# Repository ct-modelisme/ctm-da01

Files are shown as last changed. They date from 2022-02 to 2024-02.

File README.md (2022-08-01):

# CTM-DA01: Digital Sound Decoder 01

The CTM-DA01 is a sound module for modelrailway projects.
This sound module is compatible with DCC & DC train layouts.

## Licenses

The hardware is released under OpenHardware principes, and the software under OpenSource principes.

 - Hardware (PCB): [Creative Commons Attribution-ShareAlike 4.0 International License](http://creativecommons.org/licenses/by-sa/4.0/)
 - Software (Firmware): [GNU General Public License v3](https://www.gnu.org/licenses/)

## Current releases

 - Hardware (PCB): version 1.0
 - Software (Firmware): version 1.1

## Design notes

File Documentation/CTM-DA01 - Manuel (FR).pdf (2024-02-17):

## CTM-DA01

Décodeur audio configurable

La carte CTM-DA01 est un décodeur sonore, commandable par DCC ou par boutons poussoirs, permettant d’animer votre réseau de quelques bruits ou d’une ambiance sonore.

En cas de bogue, ou simplement si vous avez des suggestions, merci de me contacter à l’adresse :

cyrille.toulet@linux.com

Fonctionnalités

- Commande par DCC ou par boutons poussoirs déportés (optionnel) ;
- Configuration via Cvs ;
- Banque de sons « simples » ;
- Banque de sons à lire en boucle ;
- Banque de sons à lire aléatoirement ;
- Connexion USB série 115 200 bauds (optionnelle).

Montage

Aperçu du montage minimal

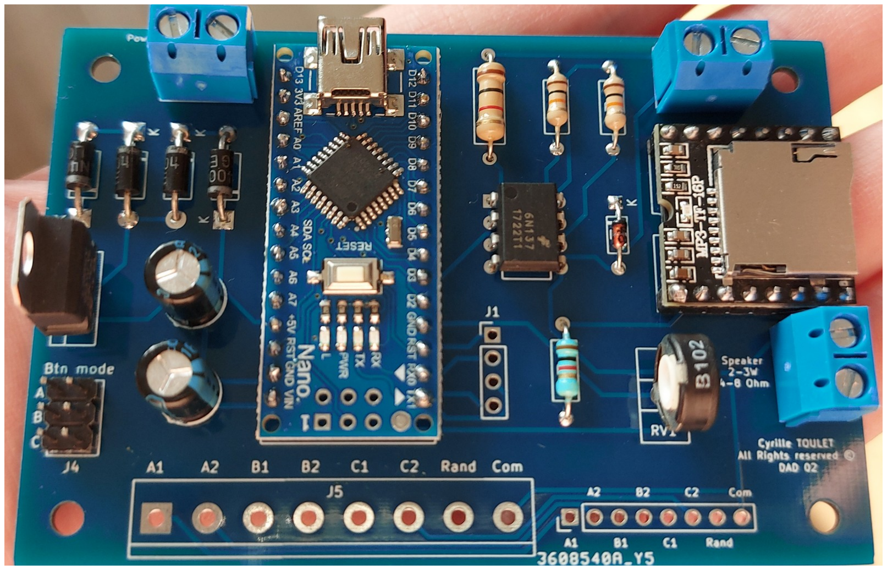
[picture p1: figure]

https://www.ct-modelisme.fr/ | CTM-DA01 | PCB 1.1 – Firmware 1.1

Liste des composants
Références | Composant | Quantité | Description
A1 | Arduino Nano | 1 | Support optionnel
C1, C2 | 220µF/16V ou 47µF/50V | 2
D1, D2, D3, D4 | 1N4007 | 4 | Ou équivalant
D5 | 1N4148 | 1
J1 | Connecteur tulipe 1x4 | 1 | Optionnel
J2, J3, J6 | Bornier à vis 1x2 | 3
J4 | Connecteur tulipe 2x3 | 1
- | Jumper | 0 à 3 | Pour la configuration des boutons
J5 | Bornier à vis 1x8 | 1 | Optionnel
J7 | Connecteur tulipe 1x8 | 1 | Optionnel
R1, R2 | 10kΩ | 2
R3 | 1kΩ (1W) | 1
R4 | 1kΩ | 1
RV1 | Vertical trim pot 1kΩ à 4,7kΩ | 1 | Type B
U1 | LM7805 | 1
U2 | 6N137 | 1
U3 | DFPlayerMini | 1 | Ou autre MP3-TF-16P
- | Carte micro-SD | 1 | Une petite suffira (ex : 2 à 4 Go)
- | Haut parleur 2 à 3 W | 1 | 4 ou 8 Ohm
https://www.ct-modelisme.fr/ | CTM-DA01 | PCB 1.1 – Firmware 1.1

Ordre de montage recommandé

Comme pour n’importe quel circuit électronique, commencez des composants les moins hauts pour terminer sur les plus hauts : diode 1N4148 (D5), puis résistances 1/4 W (toutes sauf R3), puis diodes 1N4007 (D1 à D4) et résistance 1W (R3). Ensuite, supports de CI (s’il y en a), opto-coupleur (U2) et driver audio (U3), connecteurs et borniers à vis, condensateurs 220µF (C1 et C2), trim pot (RV1) et enfin, le régulateur de tension 5V (U1).

Options

En fonction du câblage de votre réseau, vous pouvez opter pour presque chaque entrée/sortie entre utiliser un bornier, utiliser un connecteur tulipe ou à broche, ou encore souder des fils directement à la place du connecteur.

Pour rendre démontable l’arduino, vous pouvez également ajouter les supports femelles préconisés dans la liste des compostants.

Installation

Firmware

Le firmware de cette carte est disponible sur le site de CTM (https://www.ct-modelisme.fr/). Pour l’installer, il suffit de programmer votre Arduino Nano avec le dernier firmware CTM-DA01 en ligne.

Fixation

La carte électronique dispose de 4 trous de montage M3 pour être fixée avec des vis ou des supports adhésifs.

Connexions

Connectez une alimentation de 12 à 15V DC sur le connecteur « Power » (peu importe la polarité). Connectez le bus JK sur le connecteur « DCC » (pas de polarité particulière non plus). Enfin, connectez un haut-parleur de 2 à 3 W en 4 ou 8 Ohm sur le connecteur « Speaker ».

https://www.ct-modelisme.fr/ | CTM-DA01 | PCB 1.1 – Firmware 1.1

Utilisation

Configuration DCC

Ce décodeur audio n’est pas à considérer comme un décodeur d’accessoire, mais comme un décodeur de locomotive à 29 fonctions (F0 à F28).

La configuration de l’adresse s’effectue en modifiant les CVs 17 et 18 du décodeur. La carte est configurée pour utiliser les adresses longues.

Pour s’assurer de la bonne programmation des variables, effectuez deux écritures consécutives de chaque CV.
Attention : Le décodeur est compatible avec l’écriture de CVs, mais pas la lecture. Il est donc

normal de ne pas savoir lire des CVs depuis votre centrale.

Pour réinitialiser le décodeur à sa configuration d’origine (factory reset), modifiez les CVs 7 et 8 à 255.

Liste des CVs
CV(s) | Description | Valeur d’usine
1 | Adresse courte | 3
7 et 8 | Reset quand les valeurs sont à 255 | 0
17 et 18 | Adresse longue | 0 et 3 (adresse 3)

Carte des fonctions DCC
Fonctions | Description
F0 (momentané) | Arrêter la lecture en cours
F1-F10 (momentané) | Jouer le son 1 à 10 correspondant (répertoire 01)
F11-F20 (momentané) | Jouer en boucle le son 1 à 10 correspondant (répertoire 02)
F21 (momentané) | Jouer un son choisi aléatoirement (répertoire 03)
F27 (on/off) | Diminuer le volume
F28 (on/off) | Mute

Réglage du volume max

Le volume maximum (master volume) se règle avec le potentiomètre RV1 sur la carte. Certaines fonctions du décodeur peuvent diminuer le volume, mais jamais l’augmenter.

https://www.ct-modelisme.fr/ | CTM-DA01 | PCB 1.1 – Firmware 1.1

Configuration des boutons

Lorsqu’un contact est fermé entre le commun et un bouton (A/B/C 1/2 et RAND), un son est joué.

Un contact sur le bouton RAND déclenchera un son aléatoire. Pour les boutons A1, A2 , B1, B2, C1 et C2, le son joué dépendra des jumpers placés sur le connecteur J4 (Btn mode).

Sans aucun jumper, les boutons 1/2 correspondants joueront un simple son. Mais si un jumper est installé, les boutons 1/2 correspondants joueront un son en boucle.
Jumper A | Jumper B | Jumper C | Btn A1 | Btn A2 | Btn B1 | Btn B2 | Btn C1 | Btn C2
Non | Non | Non | Simple 1 | Simple 2 | Simple 3 | Simple 4 | Simple 5 | Simple 6
Non | Non | Oui | Simple 1 | Simple 2 | Simple 3 | Simple 4 | Boucle 1 | Boucle 2
Non | Oui | Non | Simple 1 | Simple 2 | Boucle 1 | Boucle 2 | Simple 3 | Simple 4
Non | Oui | Oui | Simple 1 | Simple 2 | Boucle 1 | Boucle 2 | Boucle 3 | Boucle 4
Oui | Non | Non | Boucle 1 | Boucle 2 | Simple 1 | Simple 2 | Simple 3 | Simple 4
Non | Non | Oui | Boucle 1 | Boucle 2 | Simple 1 | Simple 2 | Boucle 3 | Boucle 4
Non | Oui | Non | Boucle 1 | Boucle 2 | Boucle 3 | Boucle 4 | Simple 1 | Simple 2
Oui | Oui | Oui | Boucle 1 | Boucle 2 | Boucle 3 | Boucle 4 | Boucle 5 | Boucle 6

Ajout des sons sur la carte micro-SD

La carte micro-SD doit être formatée en FAT-32.

Elle doit contenir 3 répertoires, nommés respectivement 01, 02 et 03.
Le répertoire 01 contiendra les sons à jouer une seule fois (F1 à F10). Le répertoire 02 contiendra les sons à jouer en boucle (F11 à F20). Enfin, le répertoire 03 contiendra la collections de sons à

jouer aléatoirement (F21).

Les fichiers audio devront être encodés en MP3, et seront nommés 0XX.mp3 ou XX est remplacé par le numéro du fichier.

Par exemple, 001.mp3, 002.mp3, etc.

Attention : les fichiers audio du répertoire 03 (sons aléatoires) doivent impérativement être

nommés dans l’ordre (001.mp3, 002.mp3, etc.) ! Si un fichier intermédiaire devait être supprimé, renommez le dernier du répertoire avec l’ancien nom du fichier effacé afin qu’il y ait une continuité dans les noms de fichiers. Vous pouvez mettre jusqu’à 256 sons dans ce répertoire.

https://www.ct-modelisme.fr/ | CTM-DA01 | PCB 1.1 – Firmware 1.1

Résolution de problèmes

En cas de problème, vous pouvez obtenir des informations de déboguage en connectant la carte DAD-02 à un ordinateur.

Pour cela, connectez l’ordinateur à l’Arduino Nano enfiché sur la carte à l’aide d’un câble USB.

Puis initiez une connexion série à 115 200 bauds à l’aide du moniteur série du SDK Arduino ou de tout autre logiciel série (ex : minicom sous linux).

Exemple de mise en œuvre

Dans cet exemple, nous animerons un passage à niveau situé quelque part dans le sud, entouré d’un promeneur avec son chien, d’un cycliste qui passe non loin de là, et d’une voiture arrivant au niveau du PN.

Arborescence des fichiers sur la carte micro-SD :

## - Répertoire « 01 » :

- Fichier « 001.mp3 » (sonnerie de passage à niveau)
- Fichier « 002.mp3 » (voiture qui démarre)

## - Répertoire « 02 » :

- Fichier « 001.mp3 » (chant des cigales)

## - Répertoire « 03 » :

- Fichier « 001.mp3 » (avion qui survole la zone)
- Fichier « 002.mp3 » (sonnette de vélo)
- Fichier « 003.mp3 » (chouette qui hulotte)
- Fichier « 004.mp3 » (chien qui aboie)

Nous programmons la carte sur l’adresse DCC 1234.

Depuis la centrale, un appui sur la fonction F1 de la « locomotive » 1234 déclenchera la sonnerie du PN. Un appui sur F2 déclenchera le son d’une voiture qui démarre. L’appel à la fonction F11 jouera en boucle le chant des cigales. L’appel à la fonction F21 choisira aléatoirement un son du répertoire « 03 » et le jouera.

Supposons maintenant que le réseau dispose d’un mode « nuit », tamisant l’éclairage. L’activation de la fonction F27 diminuera le volume de lecture, permettant par exemple d’atténuer le chant des cigales.

Enfin, nous installons un bouton poussoir connecté aux broches « COM » et « RAND » de la carte, que l’on installera en façade du réseau. De cette manière, les personnes peuvent elles-mêmes déclencher un son aléatoire en appuyant sur le poussoir.

https://www.ct-modelisme.fr/ | CTM-DA01 | PCB 1.1 – Firmware 1.1

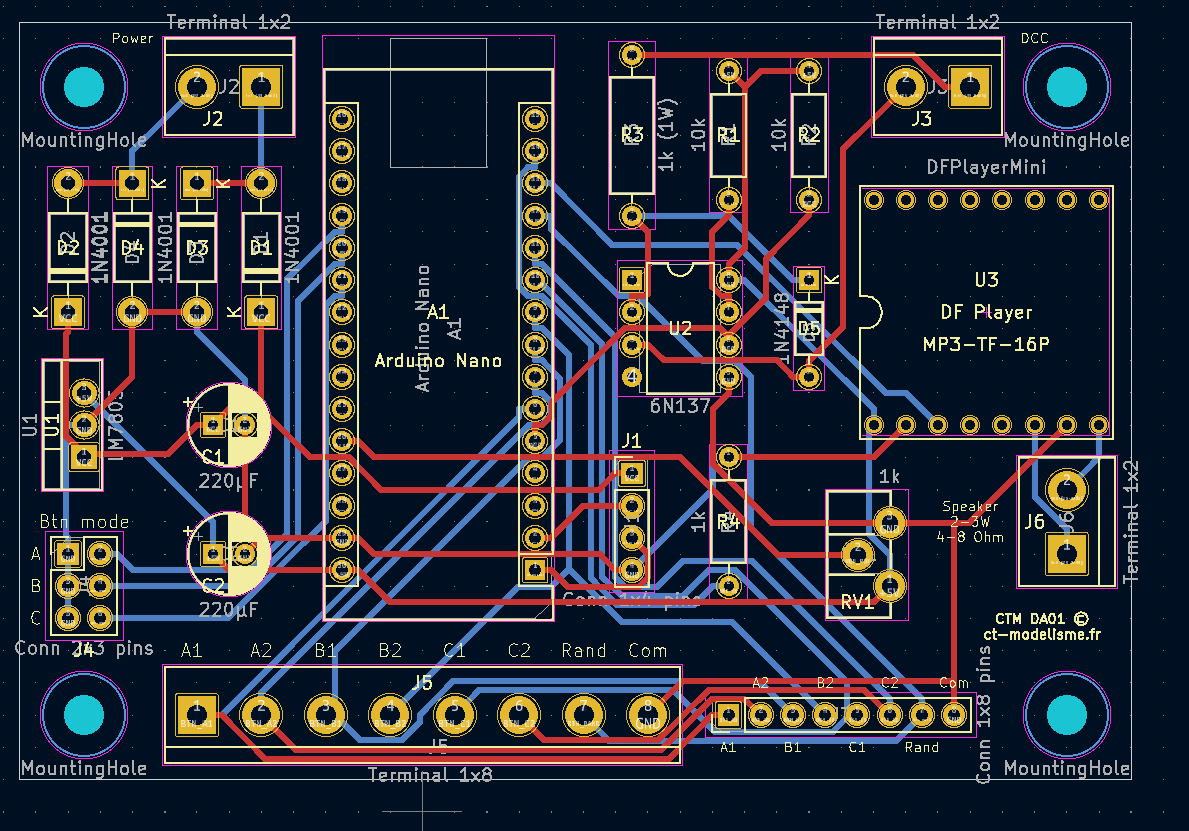
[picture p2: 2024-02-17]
Hardware/Kicad/PCB.png

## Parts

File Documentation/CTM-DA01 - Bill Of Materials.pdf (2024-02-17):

https://ct-modelisme.fr/

Références | Composant | Quantité | Description
A1 | Arduino Nano | 1 | Support optionnel
C1, C2 | 220µF | 2
D1, D2, D3, D4 | 1N4007 | 4 | Ou équivalant
D5 | 1N4148 | 1
J1 | Connecteur tulipe 1x4 | 1 | Optionnel
J2, J3, J6 | Bornier à vis 1x2 | 3
J4 | Connecteur tulipe 2x3 | 1
- | Jumper | 0 à 3 | Pour la configuration des boutons
J5 | Bornier à vis 1x8 | 1 | Optionnel
J7 | Connecteur tulipe 1x8 | 1 | Optionnel
R1, R2 | 10k | 2
R3 | 1k (1W) | 1
R4 | 1k | 1
RV1 | Trim pot 1k (vertical) | 1
U1 | LM7805 | 1
U2 | 6N137 | 1
U3 | DFPlayerMini | 1 | Ou autre MP3-TF-16P
- | Carte micro-SD | 1 | Une petite suffira (ex : 2 à 4 Go)
- | Haut parleur 2 à 3 W | 1 | 4 ou 8 Ohm
- | PCB CTM-DA01 | 1 | Carte électronique CTM-DA01

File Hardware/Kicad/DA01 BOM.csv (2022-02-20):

Source: | /home/iwa/documents/KiCAD/Digital Accessory Decoder/DAD 02/DAD 02/DAD 02.sch
Date: | Mon 23 Aug 2021 12:42:14 PM CEST
Tool: | Eeschema 5.1.10
Generator: | /usr/share/kicad/plugins/bom_csv_grouped_by_value.py
Component Count: | 27
Individual Components:
Item | Qty | Reference(s) | Value | LibPart | Footprint | Datasheet
 |  | A1 | Arduino Nano | MCU_Module:Arduino_Nano_v2.x | Module:Arduino_Nano | https://www.arduino.cc/en/uploads/Main/ArduinoNanoManual23.pdf
 |  | C1 | 220µF | Device:C_Polarized | Capacitor_THT:CP_Radial_D6.3mm_P2.50mm | ~
 |  | C2 | 220µF | Device:C_Polarized | Capacitor_THT:CP_Radial_D6.3mm_P2.50mm | ~
 |  | D1 | 1N4001 | Diode:1N4001 | Diode_THT:D_DO-41_SOD81_P10.16mm_Horizontal | http://www.vishay.com/docs/88503/1n4001.pdf
 |  | D2 | 1N4001 | Diode:1N4001 | Diode_THT:D_DO-41_SOD81_P10.16mm_Horizontal | http://www.vishay.com/docs/88503/1n4001.pdf
 |  | D3 | 1N4001 | Diode:1N4001 | Diode_THT:D_DO-41_SOD81_P10.16mm_Horizontal | http://www.vishay.com/docs/88503/1n4001.pdf
 |  | D4 | 1N4001 | Diode:1N4001 | Diode_THT:D_DO-41_SOD81_P10.16mm_Horizontal | http://www.vishay.com/docs/88503/1n4001.pdf
 |  | D5 | 1N4148 | Diode:1N4148 | Diode_THT:D_DO-35_SOD27_P7.62mm_Horizontal | https://assets.nexperia.com/documents/data-sheet/1N4148_1N4448.pdf
 |  | H1 | MountingHole | Mechanical:MountingHole | MountingHole:MountingHole_3.2mm_M3 | ~
 |  | H2 | MountingHole | Mechanical:MountingHole | MountingHole:MountingHole_3.2mm_M3 | ~
 |  | H3 | MountingHole | Mechanical:MountingHole | MountingHole:MountingHole_3.2mm_M3 | ~
 |  | H4 | MountingHole | Mechanical:MountingHole | MountingHole:MountingHole_3.2mm_M3 | ~
 |  | J1 | Conn 1x4 pins | Connector:Conn_01x04_Male | Connector_PinHeader_2.54mm:PinHeader_1x04_P2.54mm_Vertical | ~
 |  | J2 | Terminal 1x2 | Connector:Screw_Terminal_01x02 | TerminalBlock:TerminalBlock_bornier-2_P5.08mm | ~
 |  | J3 | Terminal 1x2 | Connector:Screw_Terminal_01x02 | TerminalBlock:TerminalBlock_bornier-2_P5.08mm | ~
 |  | J4 | Conn 2x3 pins | Connector_Generic:Conn_02x03_Odd_Even | Connector_PinHeader_2.54mm:PinHeader_2x03_P2.54mm_Vertical | ~
 |  | J5 | Terminal 1x8 | Connector:Screw_Terminal_01x08 | TerminalBlock:TerminalBlock_bornier-8_P5.08mm | ~
 |  | J6 | Terminal 1x2 | Connector:Screw_Terminal_01x02 | TerminalBlock:TerminalBlock_bornier-2_P5.08mm | ~
 |  | J7 | Conn 1x8 pins | Connector:Conn_01x08_Male | Connector_PinHeader_2.54mm:PinHeader_1x08_P2.54mm_Vertical | ~
 |  | R1 | 10k | Device:R | Resistor_THT:R_Axial_DIN0207_L6.3mm_D2.5mm_P10.16mm_Horizontal | ~
 |  | R2 | 10k | Device:R | Resistor_THT:R_Axial_DIN0207_L6.3mm_D2.5mm_P10.16mm_Horizontal | ~
 |  | R3 | 1k (1W) | Device:R | Resistor_THT:R_Axial_DIN0309_L9.0mm_D3.2mm_P12.70mm_Horizontal | ~
 |  | R4 | 1k | Device:R | Resistor_THT:R_Axial_DIN0207_L6.3mm_D2.5mm_P10.16mm_Horizontal | ~
 |  | RV1 | 1k | Device:R_Potentiometer_Trim | Potentiometer_THT:Potentiometer_ACP_CA9-H2,5_Horizontal | ~
 |  | U1 | LM7805 | Regulator_Linear:LM7805_TO220 | Package_TO_SOT_THT:TO-220-3_Vertical | https://www.onsemi.cn/PowerSolutions/document/MC7800-D.PDF
 |  | U2 | 6N137 | Isolator:6N137 | Package_DIP:DIP-8_W7.62mm | https://docs.broadcom.com/docs/AV02-0940EN
 |  | U3 | DFPlayerMini | DAD-02-rescue:DFPlayerMini-Audio | Module:DFRobot_DFPlayerMini_DFR0299 | https://wiki.dfrobot.com/DFPlayer_Mini_SKU_DFR0299
Collated Components:
Item | Qty | Reference(s) | Value | LibPart | Footprint | Datasheet
1 | 1 | A1 | Arduino Nano | MCU_Module:Arduino_Nano_v2.x | Module:Arduino_Nano | https://www.arduino.cc/en/uploads/Main/ArduinoNanoManual23.pdf
2 | 2 | C1, C2 | 220µF | Device:C_Polarized | Capacitor_THT:CP_Radial_D6.3mm_P2.50mm | ~
3 | 4 | D1, D2, D3, D4 | 1N4001 | Diode:1N4001 | Diode_THT:D_DO-41_SOD81_P10.16mm_Horizontal | http://www.vishay.com/docs/88503/1n4001.pdf
4 | 1 | D5 | 1N4148 | Diode:1N4148 | Diode_THT:D_DO-35_SOD27_P7.62mm_Horizontal | https://assets.nexperia.com/documents/data-sheet/1N4148_1N4448.pdf
5 | 4 | H1, H2, H3, H4 | MountingHole | Mechanical:MountingHole | MountingHole:MountingHole_3.2mm_M3 | ~
6 | 1 | J1 | Conn 1x4 pins | Connector:Conn_01x04_Male | Connector_PinHeader_2.54mm:PinHeader_1x04_P2.54mm_Vertical | ~
7 | 3 | J2, J3, J6 | Terminal 1x2 | Connector:Screw_Terminal_01x02 | TerminalBlock:TerminalBlock_bornier-2_P5.08mm | ~
8 | 1 | J4 | Conn 2x3 pins | Connector_Generic:Conn_02x03_Odd_Even | Connector_PinHeader_2.54mm:PinHeader_2x03_P2.54mm_Vertical | ~
9 | 1 | J5 | Terminal 1x8 | Connector:Screw_Terminal_01x08 | TerminalBlock:TerminalBlock_bornier-8_P5.08mm | ~
10 | 1 | J7 | Conn 1x8 pins | Connector:Conn_01x08_Male | Connector_PinHeader_2.54mm:PinHeader_1x08_P2.54mm_Vertical | ~
11 | 2 | R1, R2 | 10k | Device:R | Resistor_THT:R_Axial_DIN0207_L6.3mm_D2.5mm_P10.16mm_Horizontal | ~
12 | 1 | R3 | 1k (1W) | Device:R | Resistor_THT:R_Axial_DIN0309_L9.0mm_D3.2mm_P12.70mm_Horizontal | ~
13 | 1 | R4 | 1k | Device:R | Resistor_THT:R_Axial_DIN0207_L6.3mm_D2.5mm_P10.16mm_Horizontal | ~
14 | 1 | RV1 | 1k | Device:R_Potentiometer_Trim | Potentiometer_THT:Potentiometer_ACP_CA9-H2,5_Horizontal | ~
15 | 1 | U1 | LM7805 | Regulator_Linear:LM7805_TO220 | Package_TO_SOT_THT:TO-220-3_Vertical | https://www.onsemi.cn/PowerSolutions/document/MC7800-D.PDF
16 | 1 | U2 | 6N137 | Isolator:6N137 | Package_DIP:DIP-8_W7.62mm | https://docs.broadcom.com/docs/AV02-0940EN
17 | 1 | U3 | DFPlayerMini | DAD-02-rescue:DFPlayerMini-Audio | Module:DFRobot_DFPlayerMini_DFR0299 | https://wiki.dfrobot.com/DFPlayer_Mini_SKU_DFR0299

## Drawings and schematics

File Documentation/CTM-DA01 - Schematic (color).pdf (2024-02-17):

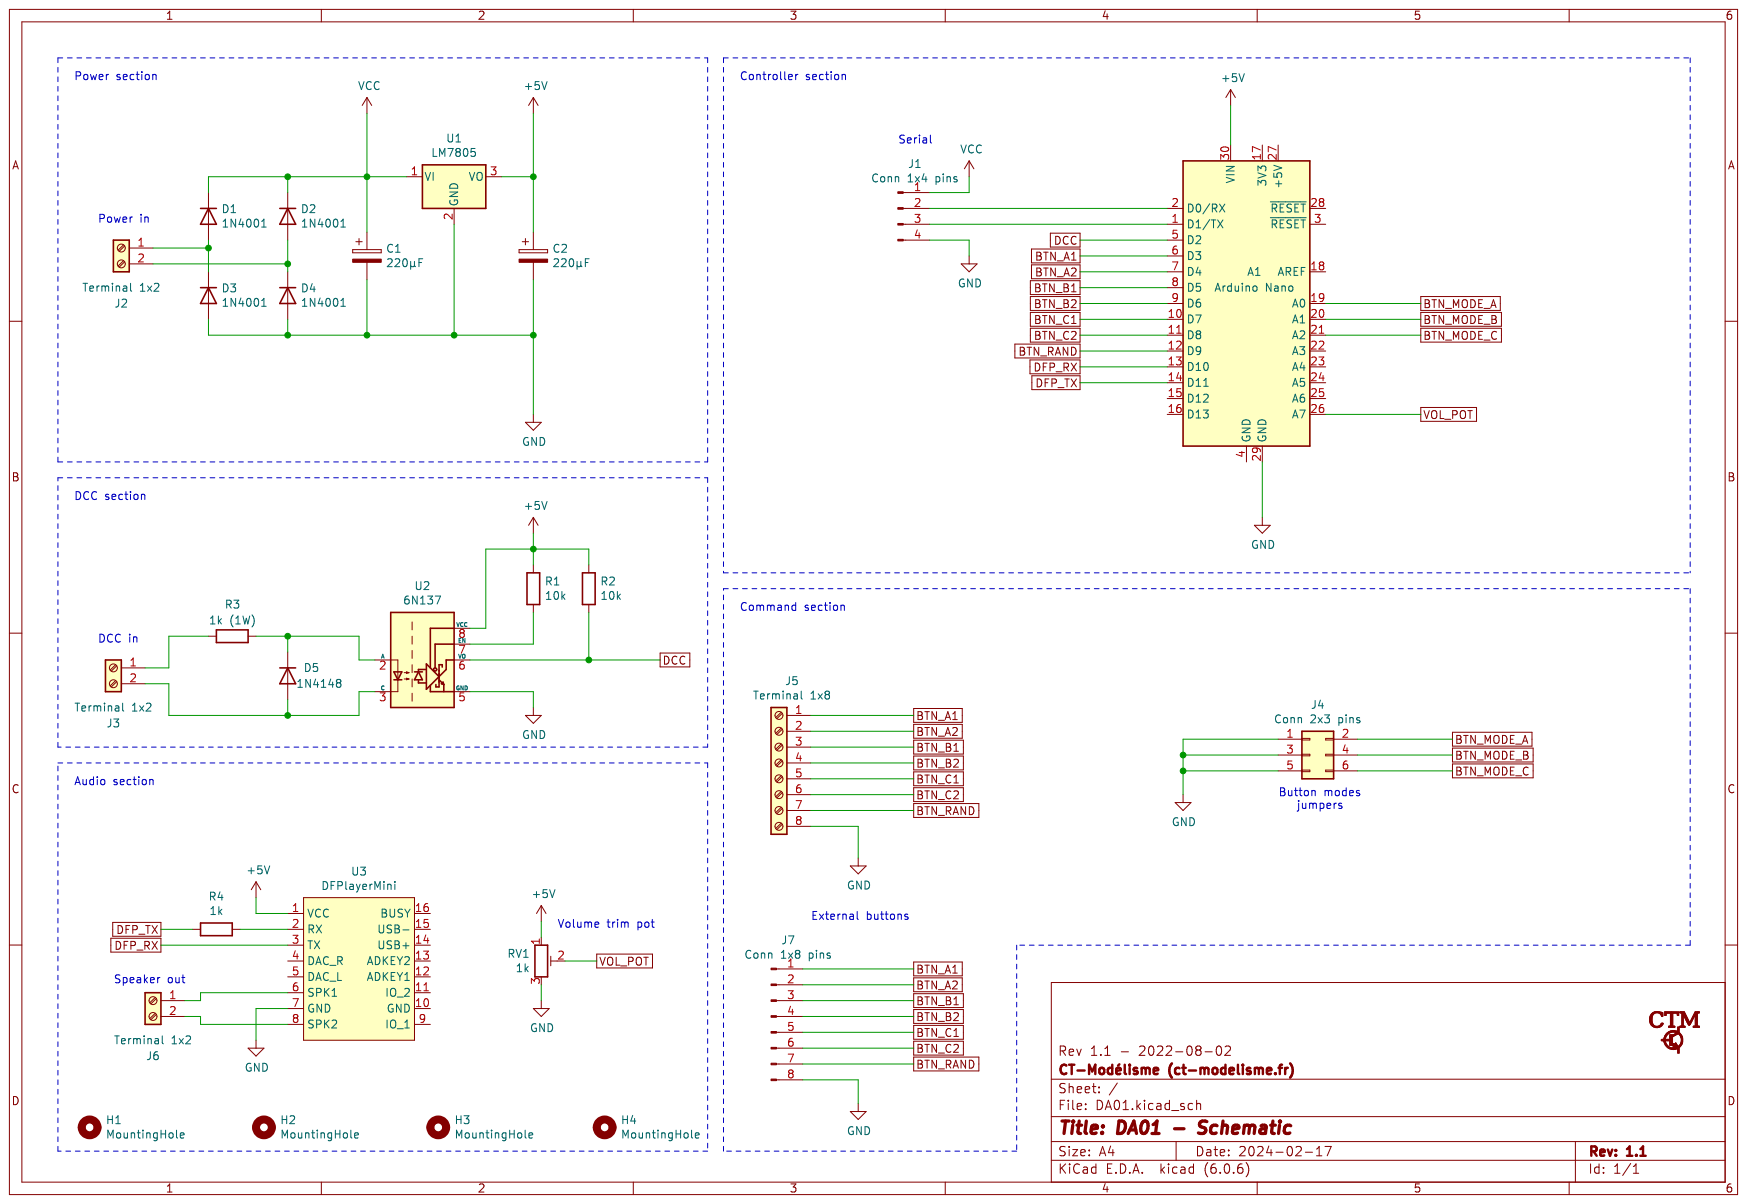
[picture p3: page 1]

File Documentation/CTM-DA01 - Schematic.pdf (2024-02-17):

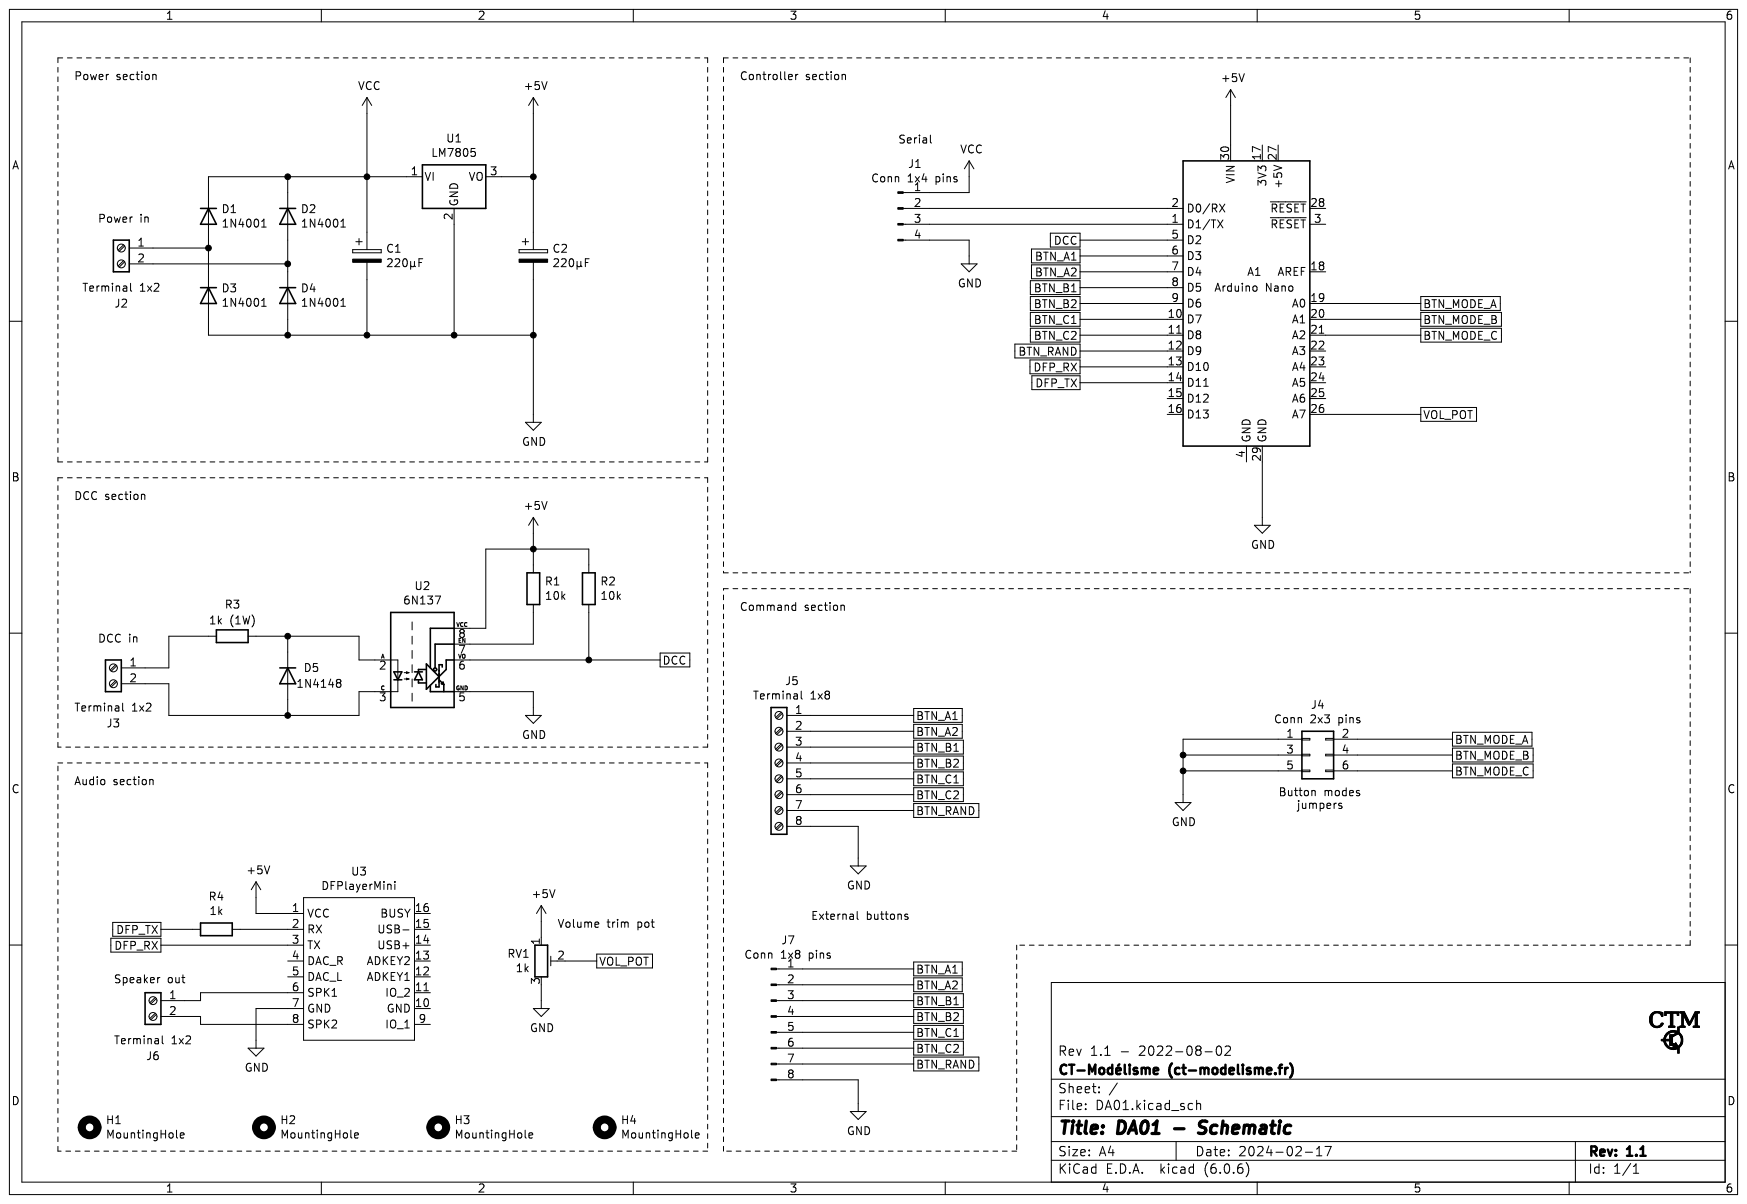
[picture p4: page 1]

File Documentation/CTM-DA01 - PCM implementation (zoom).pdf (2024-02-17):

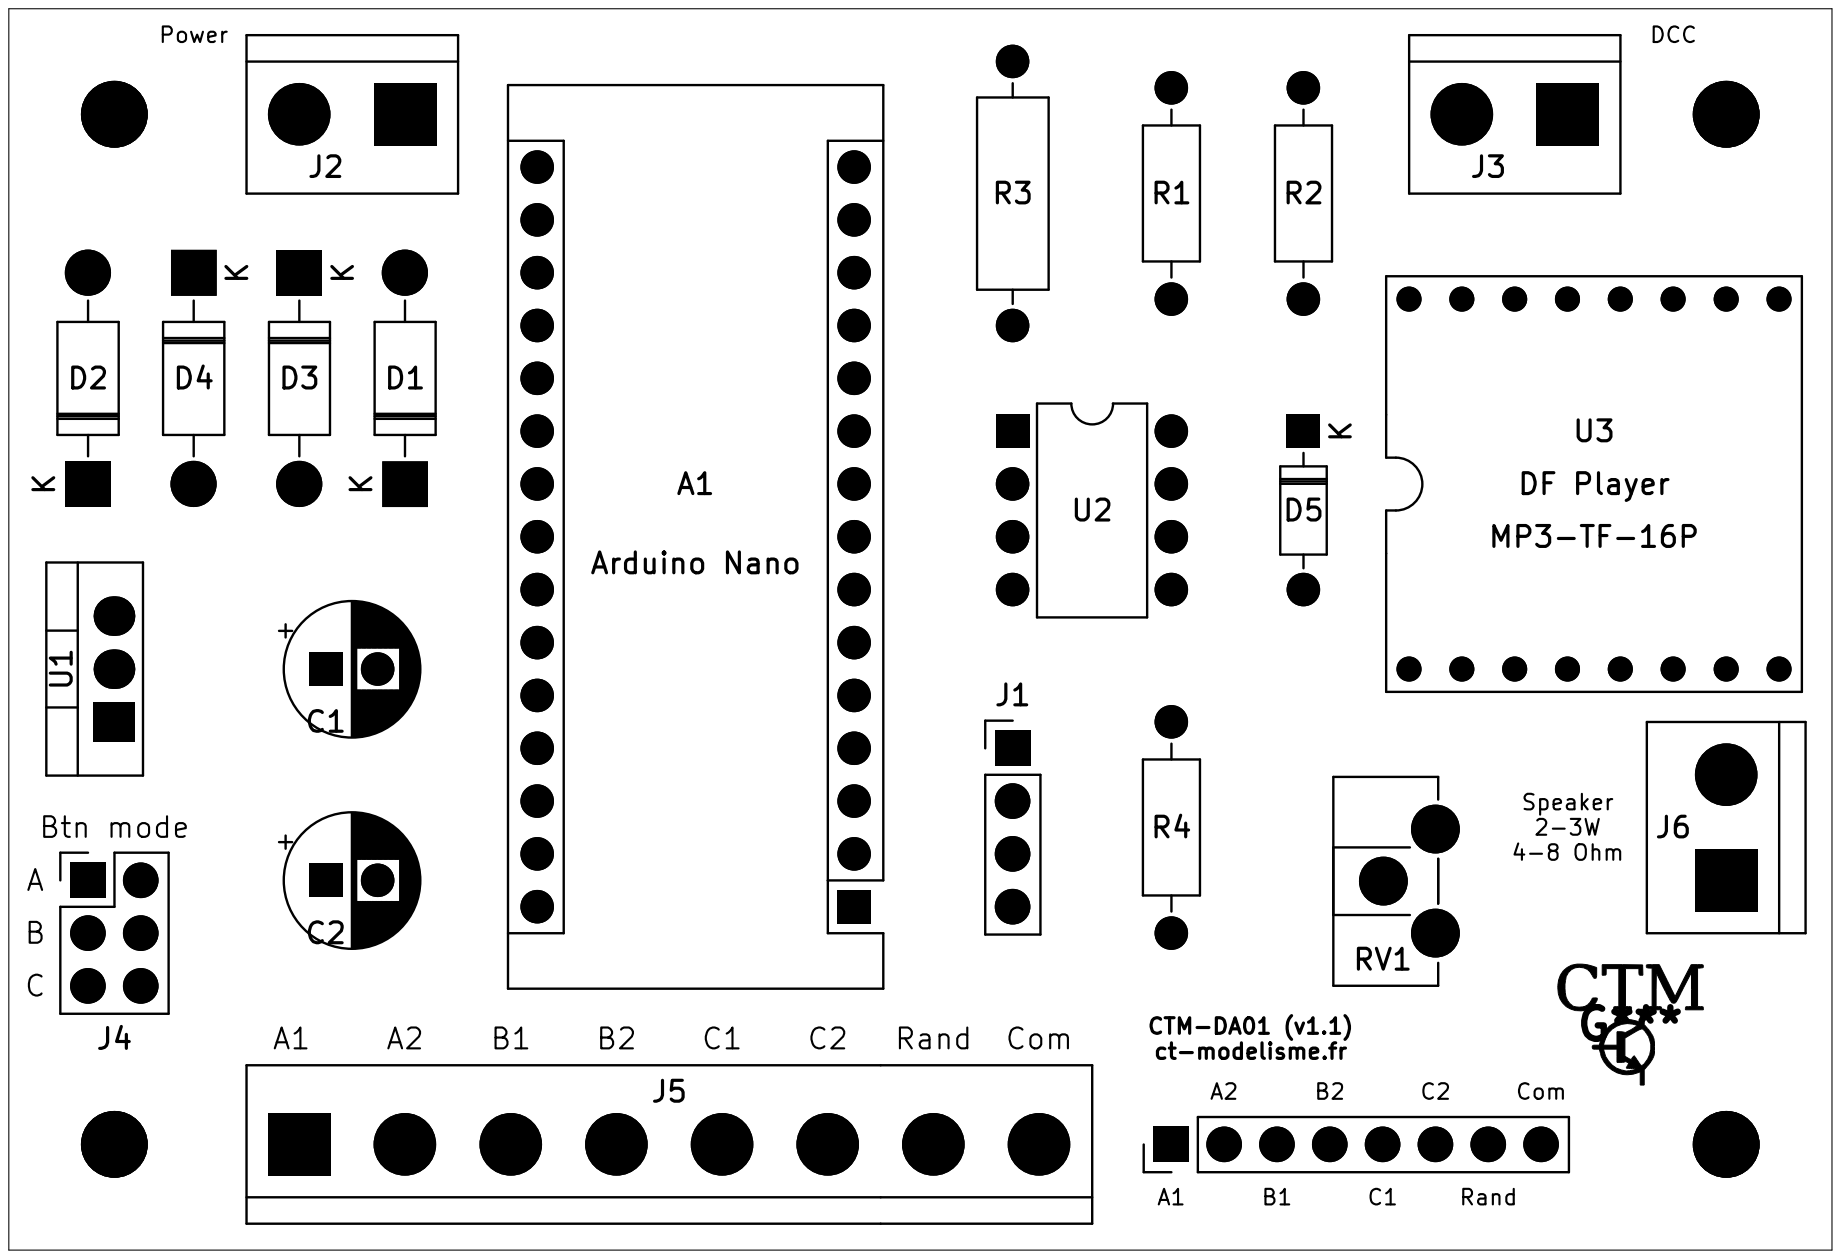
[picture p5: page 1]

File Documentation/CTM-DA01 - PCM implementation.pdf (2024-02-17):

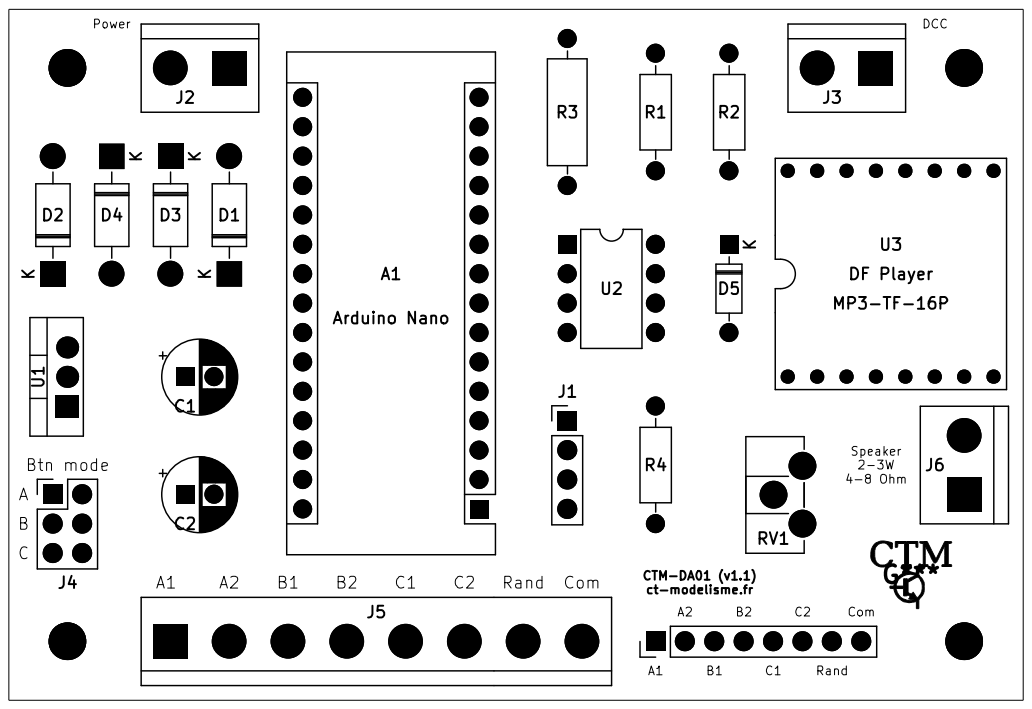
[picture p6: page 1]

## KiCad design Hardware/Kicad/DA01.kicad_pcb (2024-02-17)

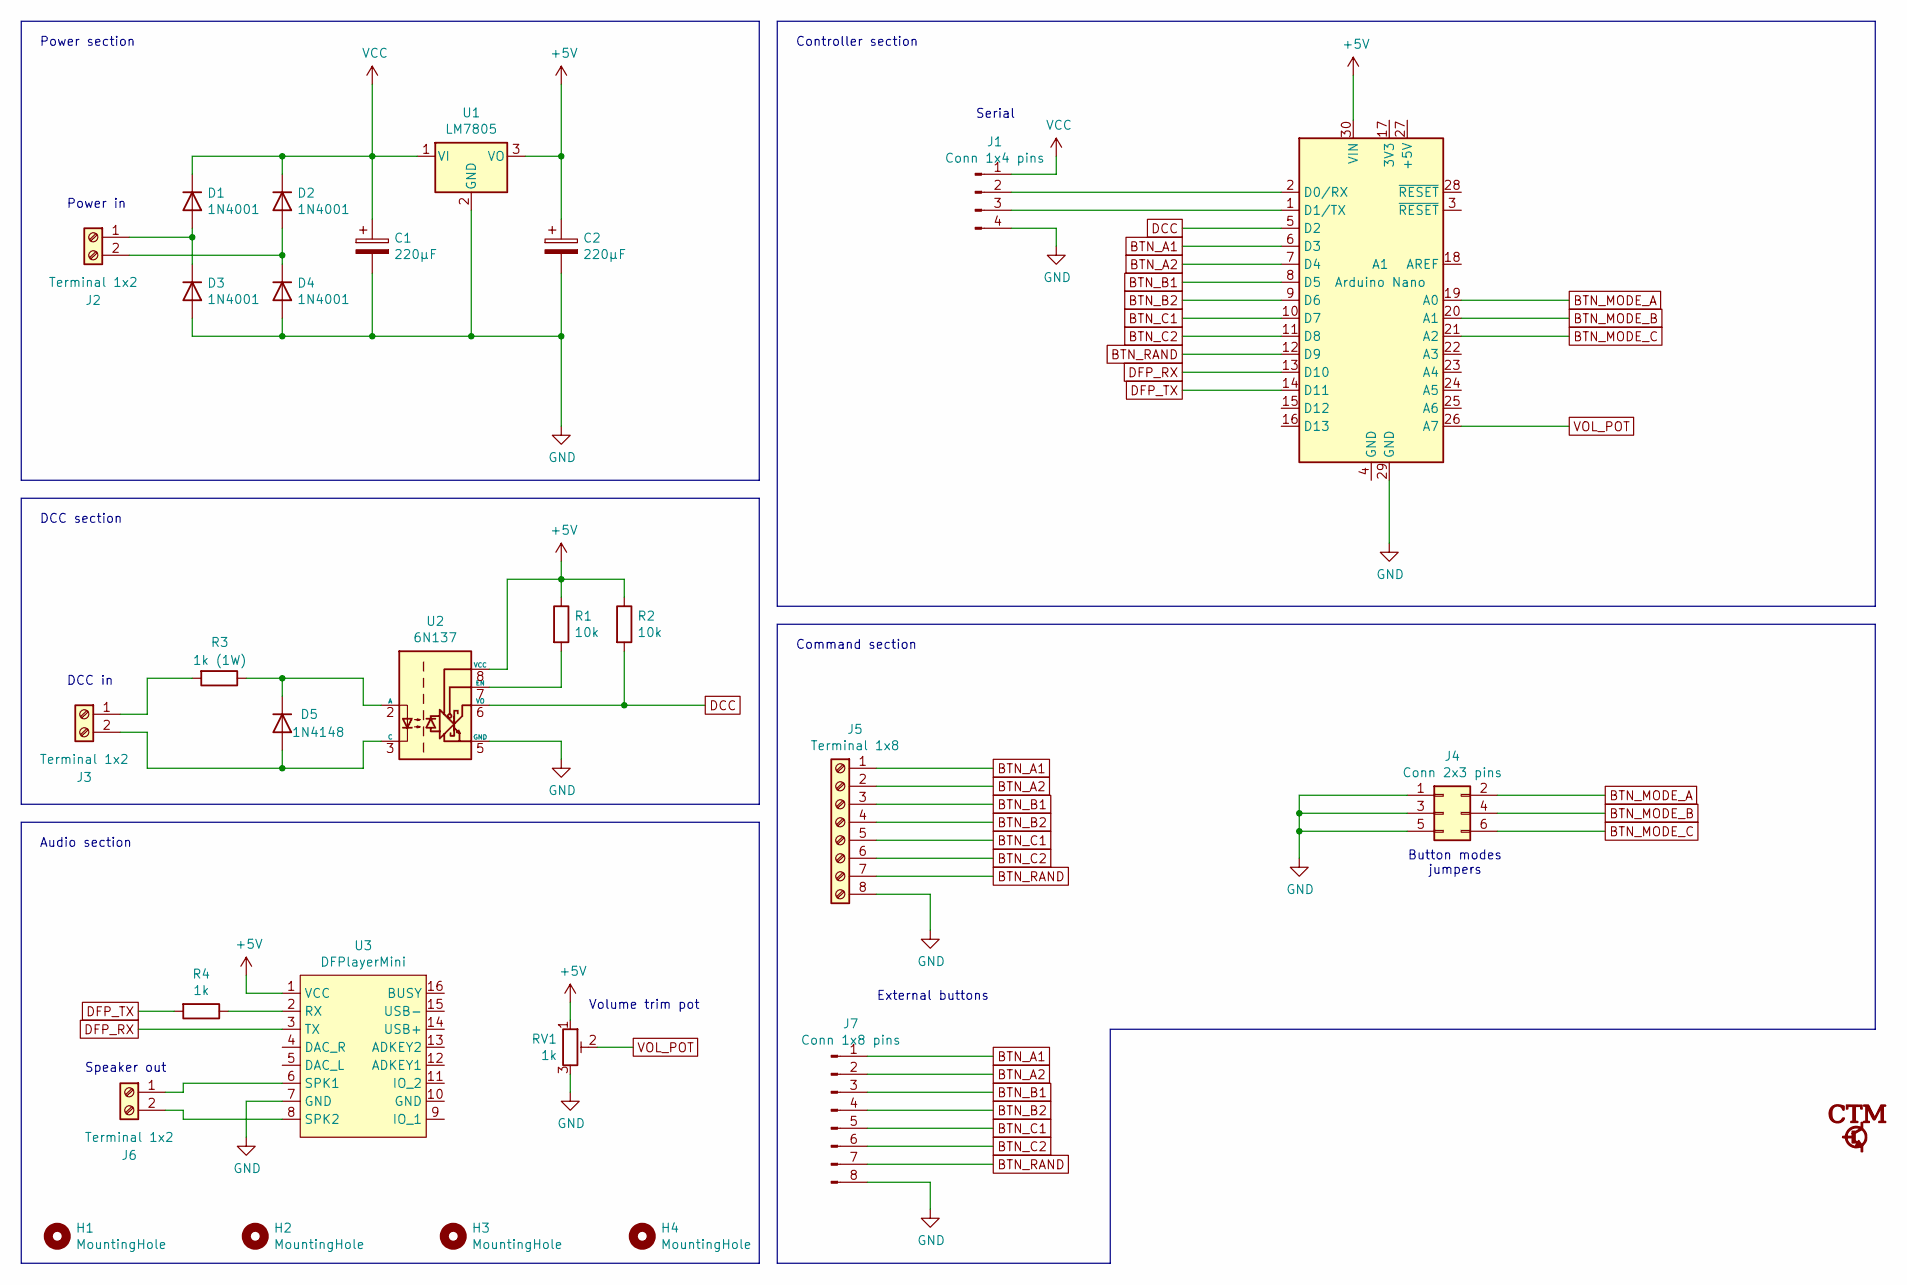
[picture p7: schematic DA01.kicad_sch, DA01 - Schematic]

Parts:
A1: Arduino Nano; Arduino_Nano
C1, C2: 220µF; CP_Radial_D6.3mm_P2.50mm
D1, D2, D3, D4: 1N4001; D_DO-41_SOD81_P10.16mm_Horizontal
D5: 1N4148; D_DO-35_SOD27_P7.62mm_Horizontal
H1, H2, H3, H4: MountingHole; MountingHole_3.2mm_M3
J1: Conn 1x4 pins; PinHeader_1x04_P2.54mm_Vertical
J2, J3, J6: Terminal 1x2; TerminalBlock_bornier-2_P5.08mm
J4: Conn 2x3 pins; PinHeader_2x03_P2.54mm_Vertical
J5: Terminal 1x8; TerminalBlock_bornier-8_P5.08mm
J7: Conn 1x8 pins; PinHeader_1x08_P2.54mm_Vertical
R1, R2: 10k; R_Axial_DIN0207_L6.3mm_D2.5mm_P10.16mm_Horizontal
R3: 1k (1W); R_Axial_DIN0309_L9.0mm_D3.2mm_P12.70mm_Horizontal
R4: 1k; R_Axial_DIN0207_L6.3mm_D2.5mm_P10.16mm_Horizontal
RV1: 1k; Potentiometer_ACP_CA9-H2,5_Horizontal
U1: LM7805; TO-220-3_Vertical
U2: 6N137; DIP-8_W7.62mm
U3: DFPlayerMini; DFRobot_DFPlayerMini_DFR0299

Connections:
+5V: A1.30 (VIN), C2.1, R1.1, R2.1, RV1.1, U1.3 (VO), U2.8 (VCC), U3.1 (VCC)
BTN_A1: A1.6 (D3), J5.1, J7.1
BTN_A2: A1.7 (D4), J5.2, J7.2
BTN_B1: A1.8 (D5), J5.3, J7.3
BTN_B2: A1.9 (D6), J5.4, J7.4
BTN_C1: A1.10 (D7), J5.5, J7.5
BTN_C2: A1.11 (D8), J5.6, J7.6
BTN_MODE_A: A1.19 (A0), J4.2
BTN_MODE_B: A1.20 (A1), J4.4
BTN_MODE_C: A1.21 (A2), J4.6
BTN_RAND: A1.12 (D9), J5.7, J7.7
DCC: A1.5 (D2), R2.2, U2.6 (VO)
DFP_RX: A1.13 (D10), U3.3 (TX)
DFP_TX: A1.14 (D11), R4.2
GND: A1.29 (GND), C1.2, C2.2, D3.2 (A), D4.2 (A), J1.4, J4.1, J4.3, J4.5, J5.8, J7.8, RV1.3, U1.2 (GND), U2.5 (GND), U3.7 (GND)
unnamed: A1.1 (D1/TX), J1.3
unnamed: A1.2 (D0/RX), J1.2
unnamed: D1.2 (A), D3.1 (K), J2.1
unnamed: D2.2 (A), D4.1 (K), J2.2
unnamed: D5.1 (K), R3.1, U2.2 (A)
unnamed: D5.2 (A), J3.2, U2.3 (C)
unnamed: J3.1, R3.2
unnamed: J6.1, U3.6 (SPK1)
unnamed: J6.2, U3.8 (SPK2)
unnamed: R1.2, U2.7 (EN)
unnamed: R4.1, U3.2 (RX)
VCC: C1.1, D1.1 (K), D2.1 (K), J1.1, U1.1 (VI)
VOL_POT: A1.26 (A7), RV1.2

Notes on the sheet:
Volume trim pot
DCC in
Power section
DCC section
Button modes jumpers
Command section
Serial
Power in
Speaker out
Audio section
External buttons
Controller section

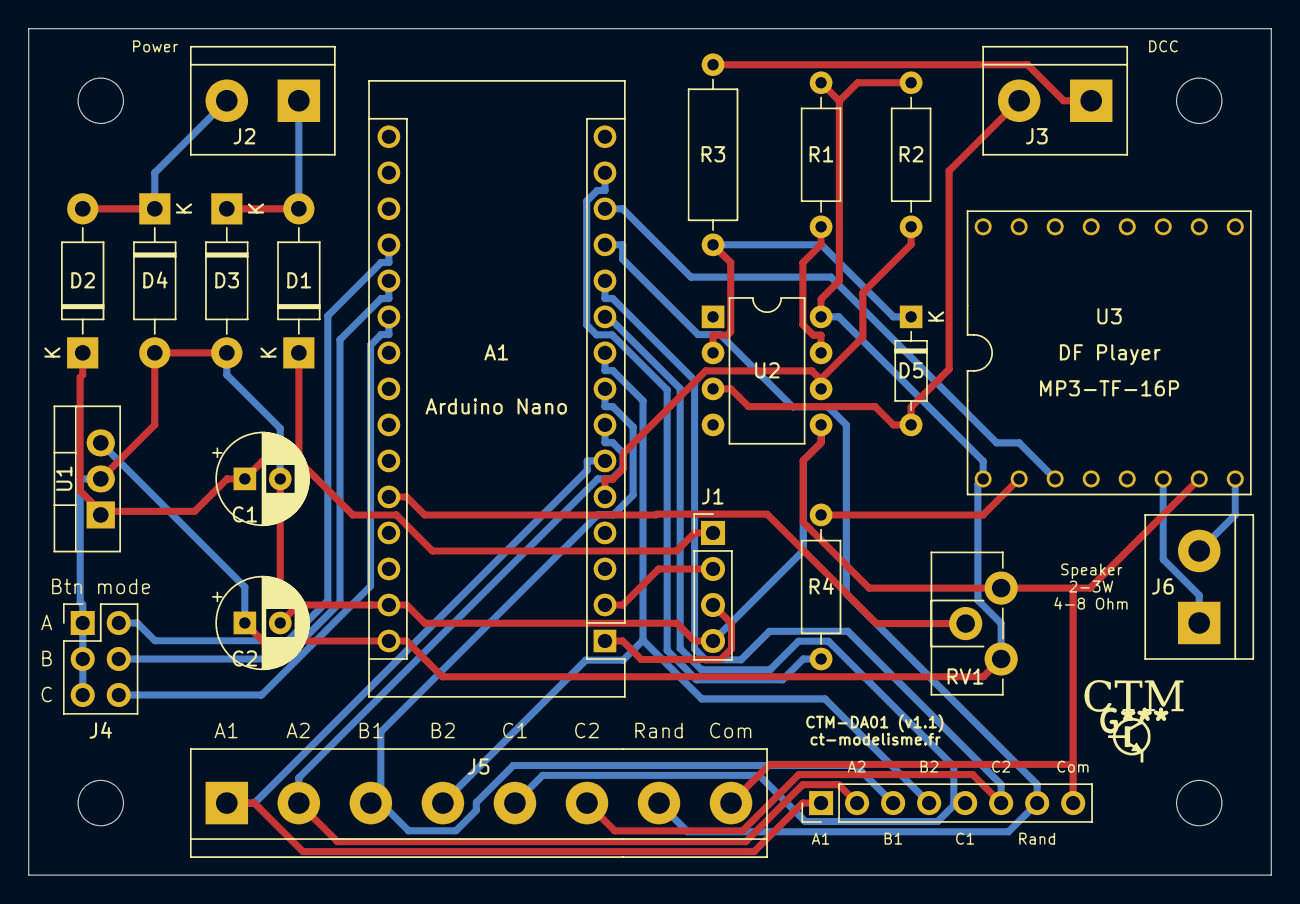
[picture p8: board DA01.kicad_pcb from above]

Board: 2 copper layers, 87.6 x 59.7 mm, 27 parts (0 on the bottom side), 28 nets.

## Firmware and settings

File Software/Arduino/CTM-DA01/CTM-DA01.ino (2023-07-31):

/**
 * CT-Modelisme (ct-modelisme.fr) - Decodeur Audio 01 (CTM-DA01.ino)
 * 
 * Requires NmraDcc library from mrrwa (https://github.com/mrrwa/NmraDcc)
 * Requires DFPlayerMini library from DFRobot (https://github.com/DFRobot/DFRobotDFPlayerMini)
 * 
 * 
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
 * 
 * Cyrille TOULET <cyrille.toulet@linux.com>
 * Sat 21 Aug 12:38:54 CEST 2021
 */


// ----------------------------------------- Configuration -------------------------------------------- //

// Libraries
#include <NmraDcc.h>                                            // DCC library
#include "SoftwareSerial.h"                                     // Serial used by DFPlayer
#include "DFRobotDFPlayerMini.h"                                // DFPlayerMini audio driver


// Constants
#define BTN_MODE_A_PIN A0                                       // The pin connected to "MODE A" jumpers
#define BTN_MODE_B_PIN A1                                       // The pin connected to "MODE B" jumpers
#define BTN_MODE_C_PIN A2                                       // The pin connected to "MODE C" jumpers
#define VOL_TRIM_PIN   A7                                       // The pin connected to volume trim pot
#define DCC_SIGNAL_PIN 2                                        // The pin connected to opto-isolator
#define BTN_A1_PIN     3                                        // The pin connected to button "A1"
#define BTN_A2_PIN     4                                        // The pin connected to button "A2"
#define BTN_B1_PIN     5                                        // The pin connected to button "B1"
#define BTN_B2_PIN     6                                        // The pin connected to button "B2"
#define BTN_C1_PIN     7                                        // The pin connected to button "C1"
#define BTN_C2_PIN     8                                        // The pin connected to button "C2"
#define BTN_RAND_PIN   9                                        // The pin connected to button "RAND"
#define PLAYER_RX_PIN  10                                       // The pin connected to serial rx of DFPlayer
#define PLAYER_TX_PIN  11                                       // The pin connected to serial tx of DFPlayer

#define DECODER_VERSION 1                                       // The decoder version used by NmraDcc lib
#define FACTORY_DCC_ADDRESS 3                                   // The default DCC address for this decoder


// Structures
struct CV                                                       // The CV structure
{
  uint16_t addr;                                                // Address of CV
  uint8_t value;                                                // Value of CV
};


// Globals
SoftwareSerial playerSerial(PLAYER_RX_PIN, PLAYER_TX_PIN);      // The audio player serial
DFRobotDFPlayerMini player;                                     // The audio player instance
NmraDcc dcc;                                                    // The DCC instance

CV factoryCVs[] =                                               // The factory default CVs
{
  // The CV Below defines the Short DCC Address
  {CV_MULTIFUNCTION_PRIMARY_ADDRESS, FACTORY_DCC_ADDRESS},      // CV 1

  // These two CVs define the Long DCC Address
  {CV_MULTIFUNCTION_EXTENDED_ADDRESS_MSB, 192},                 // CV 17
  {CV_MULTIFUNCTION_EXTENDED_ADDRESS_LSB, FACTORY_DCC_ADDRESS}, // CV 18

  // Use long address 28/128 Speed Steps
  {CV_29_CONFIG, CV29_EXT_ADDRESSING|CV29_F0_LOCATION},         // CV 29
};

uint8_t factoryCVIndex = 0;                                     // The factory CV current index

int playedLoopingSong = 0;



// ------------------------------------- Common functions --------------------------------------------- //

/**
 * Software arduino reset
 */
void (*resetArduino) (void) = 0;



// -------------------------------------- Audio functions --------------------------------------------- //

/**
 * Compute DFPlayer volume from trim pot value
 * @return: The computed volume between 0 and 30
 */
int
getVolume()
{
  return min(analogRead(VOL_TRIM_PIN)/28, 840);
}


/**
 * Play a file stored in folder "01"
 * @param id: The ID of file to play
 */
void 
playSimpleSong(int id)
{
  Serial.print("Play simple sound ");
  Serial.println(id);

  player.disableLoop();
  player.stop();
  player.playFolder(1, id);

  delay(200);
}


/**
 * Play a file stored in folder "02" in loop mode
 * @param id: The ID of file to play
 */
void 
playLoopingSong(int id)
{
  player.stop();
  player.enableLoop();
  
  if(id == playedLoopingSong)
  {
    Serial.print("Stop looping sound ");
    Serial.println(id);
    
    playedLoopingSong = 0;
  }
  else
  {
    Serial.print("Play looping sound ");
    Serial.println(id);

    playedLoopingSong = id;
    player.playFolder(2, id);
  }

  delay(200);
}


/**
 * Play a file randomly choose in folder "03"
 */
void 
playRandomSong()
{
  int randomCount = player.readFileCountsInFolder(3);
  int id = random(1, randomCount + 1);

  Serial.print("Play random sound ");
  Serial.println(id);

  player.disableLoop();
  player.stop();
  player.playFolder(3, id);

  delay(200);
}



// ---------------------------------------- DCC functions --------------------------------------------- //

/**
 * Reset CVs to factory defaults
 */
void
notifyCVResetFactoryDefault()
{
  Serial.println("Factory reset requested");
  
  // Make factoryCVIndex non-zero and equal to num CV's to be reset 
  // to flag to the loop() function that a reset to Factory Defaults needs to be done
  factoryCVIndex = sizeof(factoryCVs) / sizeof(CV);
};


/**
 * Apply factory reset if requested by notifyCVResetFactoryDefault (CV 7 and 8 to "255")
 */
void
applyFactoryReset()
{
  if(factoryCVIndex && dcc.isSetCVReady())
  {
    // Decrement first as initially it is the size of the array 
    factoryCVIndex--; 
    
    dcc.setCV(
      factoryCVs[factoryCVIndex].addr, 
      factoryCVs[factoryCVIndex].value
    );

    if(factoryCVIndex == 0)
    {
      Serial.println("All CVs reset at factory defaults. Reboot in progress...");
      delay(200);
      resetArduino();
    }
  }
}


/**
 * Notify CV ack
 */
void
notifyCVAck()
{
  digitalWrite(LED_BUILTIN, HIGH);
  delay(8);
  digitalWrite(LED_BUILTIN, LOW);
}


/**
 * Notify a change to a CV
 */
void
notifyCVChange(uint16_t cv, uint8_t value)
{
  Serial.print("New value for CV ");
  Serial.print(cv);
  Serial.print(": ");
  Serial.println(value);

  if(dcc.isSetCVReady())
  {
    dcc.setCV(cv, value);

    Serial.print("CV ");
    Serial.print(cv);
    Serial.print(" changed to ");
    Serial.println(value);
  }
}


/**
 * Notify DCC functions (F0 to F28) according to following map:
 *  - F0 = Stop played sounds
 *  
 *  - F1-F10 = Play simple sounds 1 to 10
 *  - F11-F20 = Play loop sounds 1 to 10
 *  - F21 = Play random sound
 *  
 *  - F27 = Turn down the volume
 *  - F28 = Mute (on/off)
 *  
 * @param addr: The DCC address
 * @param type: The DCC address type (short/long)
 * @param group: The functions group
 * @param state: The functions state
 */
void 
notifyDccFunc(uint16_t addr, DCC_ADDR_TYPE type, FN_GROUP group, uint8_t state)
{
  if(addr != ((type == DCC_ADDR_SHORT)? 
    dcc.getCV(CV_MULTIFUNCTION_PRIMARY_ADDRESS): 
    ((dcc.getCV(CV_MULTIFUNCTION_EXTENDED_ADDRESS_MSB) - 192) << 8) + dcc.getCV(CV_MULTIFUNCTION_EXTENDED_ADDRESS_LSB)
  ))
    return;


  switch(group)
  {
    case FN_0_4:
      // Only process F0 in this packet if we're not in Speed Step 14 Mode
      if(dcc.getCV(CV_29_CONFIG) & CV29_F0_LOCATION)
        if(state & FN_BIT_00)
        {
          player.disableLoop();
          player.stop();
        }

      if(state & FN_BIT_01)
        playSimpleSong(1);
      if(state & FN_BIT_02)
        playSimpleSong(2);
      if(state & FN_BIT_03)
        playSimpleSong(3);
      if(state & FN_BIT_04)
        playSimpleSong(4);
      break;
    
    case FN_5_8:
      if(state & FN_BIT_05)
        playSimpleSong(5);
      if(state & FN_BIT_06)
        playSimpleSong(6);
      if(state & FN_BIT_07)
        playSimpleSong(7);
      if(state & FN_BIT_08)
        playSimpleSong(8);
      break;
    
    case FN_9_12:
      if(state & FN_BIT_09)
        playSimpleSong(9);
      if(state & FN_BIT_10)
        playSimpleSong(10);
        
      if(state & FN_BIT_11)
        playLoopingSong(1);
      if(state & FN_BIT_12)
        playLoopingSong(2);
      break;

    case FN_13_20:
      if(state & FN_BIT_13)
        playLoopingSong(3);
      if(state & FN_BIT_14)
        playLoopingSong(4);
      if(state & FN_BIT_15)
        playLoopingSong(5);
      if(state & FN_BIT_16)
        playLoopingSong(6);
      if(state & FN_BIT_17)
        playLoopingSong(7);
      if(state & FN_BIT_18)
        playLoopingSong(8);
      if(state & FN_BIT_19)
        playLoopingSong(9);
      if(state & FN_BIT_20)
        playLoopingSong(10);
      break;
  
    case FN_21_28:
      if(state & FN_BIT_21)
      {
        playRandomSong();
      }
      if(state & FN_BIT_28)
      {
        player.volume(0);
        Serial.println("Muted");
      }
      else if(state & FN_BIT_27)
      {
        player.volume((int) getVolume() / 1.5);
        Serial.println("Lower volume");
      }
      else
        player.volume(getVolume());
      break;  
  }
}



// -------------------------------------- Buttons functions ------------------------------------------- //


/**
 * 
 */
void
processButtons()
{
  int modeA = digitalRead(BTN_MODE_A_PIN);
  int modeB = digitalRead(BTN_MODE_B_PIN);
  int modeC = digitalRead(BTN_MODE_C_PIN);

  if(!digitalRead(BTN_RAND_PIN))
  {
    playRandomSong();
  }
  else if(!digitalRead(BTN_A1_PIN))
  {
    if(modeA)
      playSimpleSong(1);
    else
      playLoopingSong(1);

    // Software anti-rebound
    do delay(200); while(!digitalRead(BTN_A1_PIN));
  }
  else if(!digitalRead(BTN_A2_PIN))
  {
    if(modeA)
      playSimpleSong(2);
    else
      playLoopingSong(2);

    // Software anti-rebound
    do delay(200); while(!digitalRead(BTN_A2_PIN));
  }
  else if(!digitalRead(BTN_B1_PIN))
  {
    if(modeA && modeB)
      playSimpleSong(3);
    else if(modeA && !modeB)
      playLoopingSong(1);
    else if(!modeA && modeB)
      playSimpleSong(1);
    else if(!modeA && !modeB)
      playLoopingSong(3);

    // Software anti-rebound
    do delay(200); while(!digitalRead(BTN_B1_PIN));
  }
  else if(!digitalRead(BTN_B2_PIN))
  {
    if(modeA && modeB)
      playSimpleSong(4);
    else if(modeA && !modeB)
      playLoopingSong(2);
    else if(!modeA && modeB)
      playSimpleSong(2);
    else if(!modeA && !modeB)
      playLoopingSong(4);

    // Software anti-rebound
    do delay(200); while(!digitalRead(BTN_B2_PIN));
  }
  else if(!digitalRead(BTN_C1_PIN))
  {
    if(modeA)
    {
      if(modeB && modeC)
        playSimpleSong(5);
      else if(modeB && !modeC)
        playLoopingSong(1);
      else if(!modeB && modeC)
        playSimpleSong(3);
      else if(!modeB && !modeC)
        playLoopingSong(3);
    }
    else
    {
      if(modeB && modeC)
        playSimpleSong(3);
      else if(modeB && !modeC)
        playLoopingSong(3);
      else if(!modeB && modeC)
        playSimpleSong(1);
      else if(!modeB && !modeC)
        playLoopingSong(5);
    }

    // Software anti-rebound
    do delay(200); while(!digitalRead(BTN_C1_PIN));
  }
  else if(!digitalRead(BTN_C2_PIN))
  {
    if(modeA)
    {
      if(modeB && modeC)
        playSimpleSong(6);
      else if(modeB && !modeC)
        playLoopingSong(2);
      else if(!modeB && modeC)
        playSimpleSong(4);
      else if(!modeB && !modeC)
        playLoopingSong(4);
    }
    else
    {
      if(modeB && modeC)
        playSimpleSong(4);
      else if(modeB && !modeC)
        playLoopingSong(4);
      else if(!modeB && modeC)
        playSimpleSong(2);
      else if(!modeB && !modeC)
        playLoopingSong(6);
    }

    // Software anti-rebound
    do delay(200); while(!digitalRead(BTN_C2_PIN));
  }
}


// ---------------------------------------- Main programm --------------------------------------------- //

/** 
 * Arduino setup
 */
void setup() {  
  Serial.begin(115200);
  playerSerial.begin(9600);
  
  Serial.println("\n\n------");
  Serial.println("Initializing microcontroller...");
  Serial.println(" - Serial communication initialized");

  pinMode(BTN_MODE_A_PIN, INPUT_PULLUP);
  pinMode(BTN_MODE_B_PIN, INPUT_PULLUP);
  pinMode(BTN_MODE_C_PIN, INPUT_PULLUP);
  pinMode(BTN_A1_PIN, INPUT_PULLUP);
  pinMode(BTN_A2_PIN, INPUT_PULLUP);
  pinMode(BTN_B1_PIN, INPUT_PULLUP);
  pinMode(BTN_B2_PIN, INPUT_PULLUP);
  pinMode(BTN_C1_PIN, INPUT_PULLUP);
  pinMode(BTN_C2_PIN, INPUT_PULLUP);
  pinMode(BTN_RAND_PIN, INPUT_PULLUP);

  Serial.println(" - Inputs/Outputs initialized");
  Serial.println("\nInitializing audio driver...");
  
  if(!player.begin(playerSerial))
  {
    Serial.println(" - Error: unable to initialize driver. Is SD card inserted?\n");
    while(true);
  }

  Serial.println(" - MP3-TF-16P driver loaded");

  player.setTimeOut(500);
  player.EQ(DFPLAYER_EQ_NORMAL);
  player.volume(getVolume());

  Serial.println(" - MP3-TF-16P driver configured");
  Serial.println("\nInitializing DCC decoder...");

  dcc.pin(0, DCC_SIGNAL_PIN, 0);
  dcc.init(MAN_ID_DIY, DECODER_VERSION, FLAGS_AUTO_FACTORY_DEFAULT, 0);

  Serial.print(" - Short DCC address: ");
  Serial.println(dcc.getCV(CV_MULTIFUNCTION_PRIMARY_ADDRESS));
  Serial.print(" - Long DCC address: ");
  Serial.println(((dcc.getCV(CV_MULTIFUNCTION_EXTENDED_ADDRESS_MSB) - 192) << 8) + dcc.getCV(CV_MULTIFUNCTION_EXTENDED_ADDRESS_LSB));

  Serial.println("\nInitializing completed!");
  Serial.println("CT-Modelisme - Decodeur Audio 01");
  Serial.println("Firmware v1.1");
  Serial.println("Please visit https://ct-modelisme.fr/");
  Serial.println("------\n");
}



/** 
 * Arduino main loop
 */
void loop() {
  // Process DCC packets
  dcc.process();

  // Call factory reset subroutine
  applyFactoryReset();

  // Buttons
  processButtons();

  // Parse audio player messages
  if(player.available())
  {
    switch(player.readType())
    {
      case TimeOut:
        Serial.println("Time out!");
        break;
      case WrongStack:
        Serial.println("Stack wrong!");
        break;
      case DFPlayerCardInserted:
        Serial.println("Card inserted!");
        break;
      case DFPlayerCardRemoved:
        Serial.println("Card removed!");
        break;
      case DFPlayerCardOnline:
        Serial.println("Card online!");
        break;
      case DFPlayerError:
        Serial.print("DFPlayer error: ");
        switch (player.read()) {
          case Busy:
            Serial.println(F("card not found"));
            break;
          case FileMismatch:
            Serial.println(F("cannot find file"));
            break;
          default:
            break;
        }
        break;
      default:
        break;
    }
  }
}

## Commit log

2022-02-20 Extract the v1.0 of PCB
    [BOM.ods, DAD 02 BOM.csv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]
2022-02-20 Public release of firmware v1.1
    [Buttons map.ods]
2022-08-02 Kicad refactoring
    [DA01 BOM.csv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]
2024-02-17 Refactoring and documentation
    [CTM-DA01 - Bill Of Materials.ods, DA01 BOM.csv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]
2024-02-17 Add CTM in cartridge & PCB
    [DA01.kicad_pcb, DA01.kicad_sch]

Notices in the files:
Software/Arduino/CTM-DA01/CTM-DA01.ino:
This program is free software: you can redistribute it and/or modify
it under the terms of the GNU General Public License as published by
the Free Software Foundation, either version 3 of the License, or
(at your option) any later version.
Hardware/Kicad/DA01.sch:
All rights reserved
